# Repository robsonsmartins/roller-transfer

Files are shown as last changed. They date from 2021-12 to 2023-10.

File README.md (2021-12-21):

# PCB Roller Transfer Machine
The PCB Roller Transfer Machine (or Laminator Machine) is a machine designed to thermally transfer toner printed on paper to a blank Printed Circuit Board.

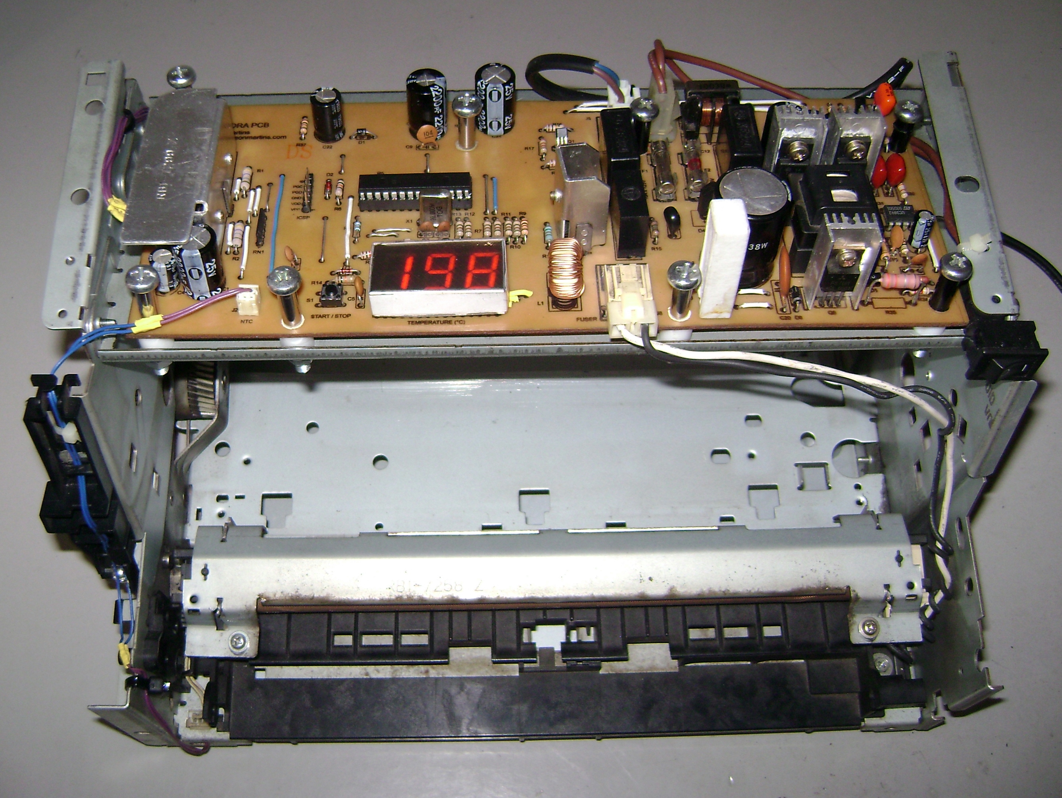
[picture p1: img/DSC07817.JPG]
PCB Roller Transfer Machine


Project site: [PCB Roller Transfer Machine Project](https://www.robsonmartins.com/content/eletr/projects/laminadora/)

[][cc-by-nc-sa]

This work is licensed under a
[Creative Commons Attribution-NonCommercial-ShareAlike 4.0 International License][cc-by-nc-sa].

[][cc-by-nc-sa]

[cc-by-nc-sa]: http://creativecommons.org/licenses/by-nc-sa/4.0/
[cc-by-nc-sa-image]: https://licensebuttons.net/l/by-nc-sa/4.0/88x31.png
[cc-by-nc-sa-shield]: https://img.shields.io/badge/License-CC%20BY--NC--SA%204.0-lightgrey.svg

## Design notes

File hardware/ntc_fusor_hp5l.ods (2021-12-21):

Tabela de Resistência X Temperatura do NTC do Fusor da HP 5L
Valor deRBalance (em Ω): |  | 18000
Temperatura (°C) | NTC Resistência (Ω) | Valor do ADC
20 | 440000,000 | 40
22 | 402072,277 | 44
24 | 368091,613 | 48
26 | 337586,262 | 52
28 | 310147,457 | 56
30 | 285420,188 | 61
32 | 263095,443 | 66
34 | 242903,659 | 71
36 | 224609,187 | 76
38 | 208005,600 | 82
40 | 192911,702 | 87
42 | 179168,131 | 93
44 | 166634,456 | 100
46 | 155186,703 | 106
48 | 144715,217 | 113
50 | 135122,842 | 120
52 | 126323,343 | 128
54 | 118240,047 | 135
56 | 110804,672 | 143
58 | 103956,307 | 151
60 | 97640,534 | 159
62 | 91808,656 | 168
64 | 86417,030 | 177
66 | 81426,490 | 185
68 | 76801,828 | 194
70 | 72511,356 | 204
72 | 68526,512 | 213
74 | 64821,517 | 223
76 | 61373,072 | 232
78 | 58160,093 | 242
80 | 55163,476 | 252
82 | 52365,890 | 262
84 | 49751,593 | 272
86 | 47306,268 | 282
88 | 45016,880 | 292
90 | 42871,548 | 303
92 | 40859,430 | 313
94 | 38970,621 | 324
96 | 37196,062 | 334
98 | 35527,461 | 344
100 | 33957,218 | 355
102 | 32478,361 | 365
104 | 31084,488 | 376
106 | 29769,713 | 386
108 | 28528,624 | 396
110 | 27356,233 | 406
112 | 26247,944 | 417
114 | 25199,517 | 427
116 | 24207,035 | 437
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

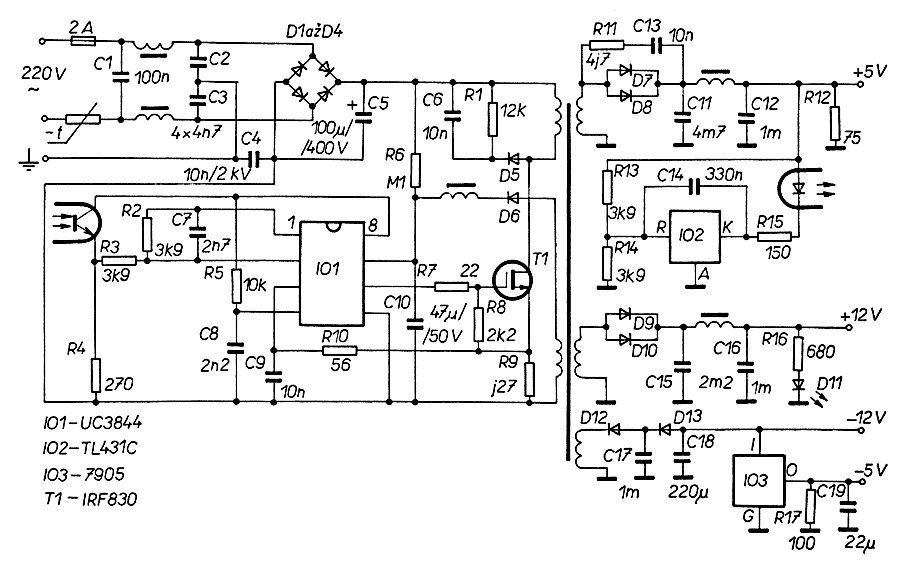
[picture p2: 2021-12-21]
hardware/psu_uc3844.gif

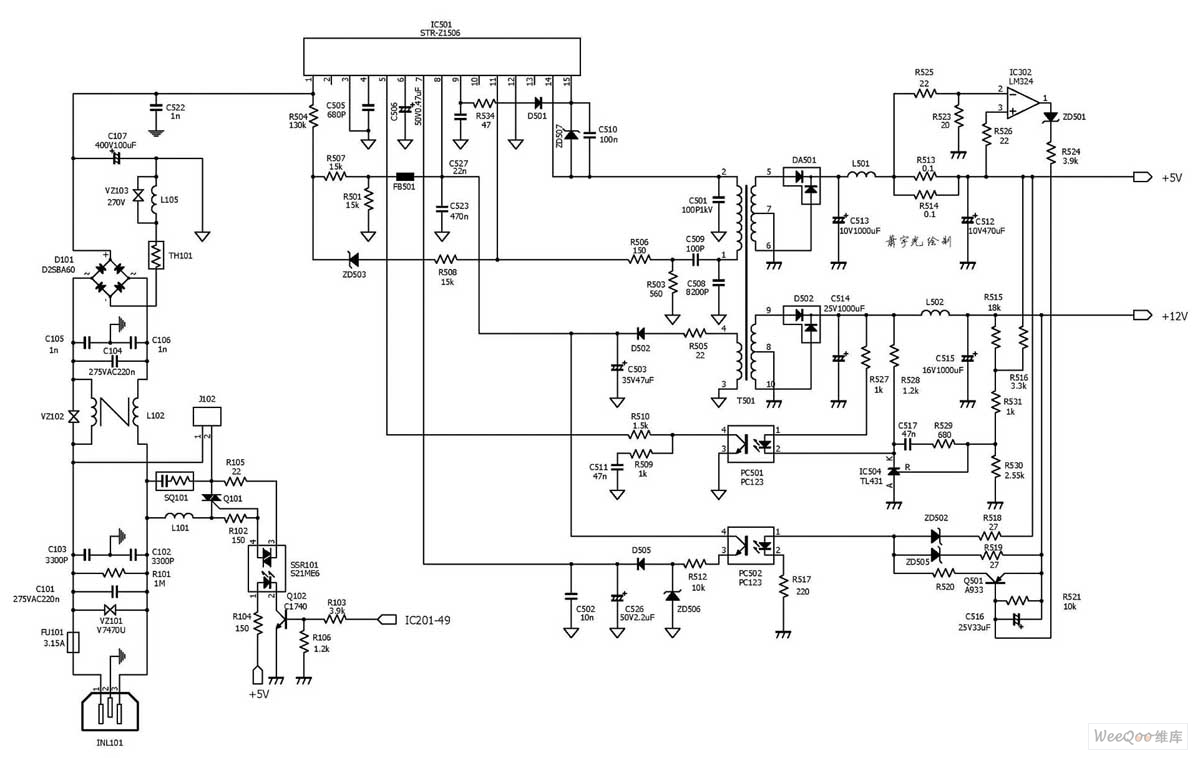
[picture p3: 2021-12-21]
hardware/psu_laserjet6l.jpg

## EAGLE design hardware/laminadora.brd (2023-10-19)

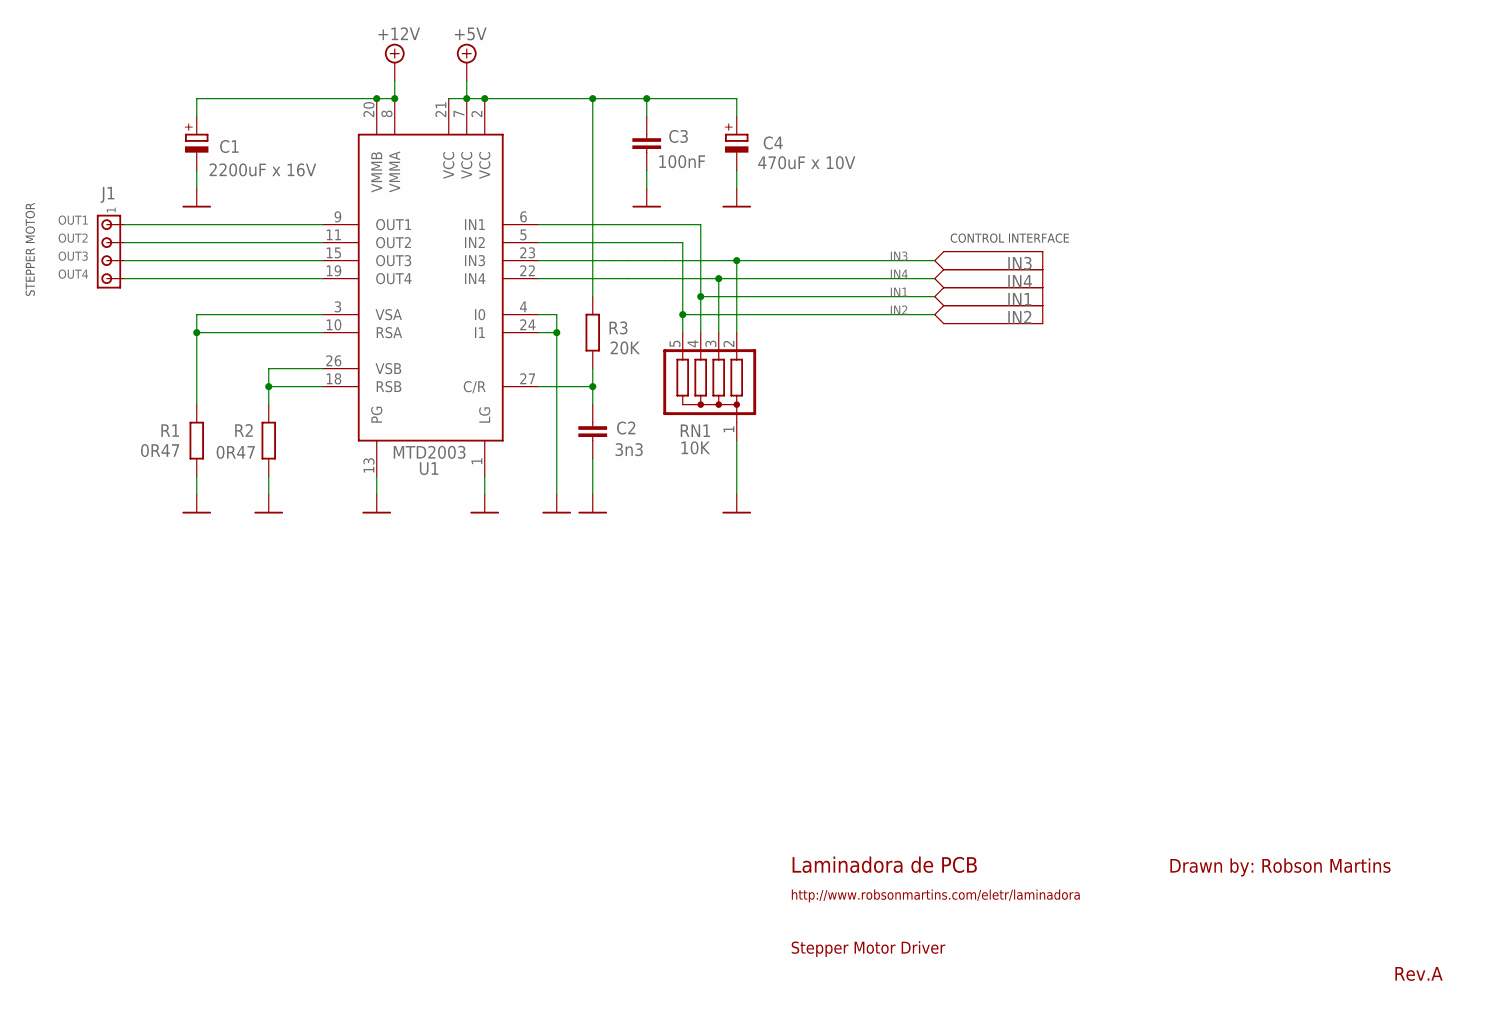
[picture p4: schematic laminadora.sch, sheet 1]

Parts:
C1: 2200uF x 16V; E5-13
C2: 3n3; C050-025X075
C3: 100nF; C050-025X075
C4: 470uF x 10V; E5-8,5
J1: A20-04
R1, R2: 0R47; 0309/12
R3: 20K; 0207/10
RN1: 10K; SIL5
U1: MTD2003; ZIP27SINK

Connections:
+5V: C3.1, C4.+, R3.2, U1.2 (VCC), U1.7 (VCC), U1.21 (VCC); also elsewhere on the board
+12V: C1.+, U1.8 (VMMA), U1.20 (VMMB); also elsewhere on the board
CR: C2.1, R3.1, U1.27 (C/R)
GND: C1.-, C2.2, C3.2, C4.-, R1.1, R2.1, RN1.1, U1.1 (LG), U1.4 (I0), U1.13 (PG), U1.24 (I1); also elsewhere on the board
IN1: RN1.4, U1.6 (IN1); also elsewhere on the board
IN2: RN1.5, U1.5 (IN2); also elsewhere on the board
IN3: RN1.2, U1.23 (IN3); also elsewhere on the board
IN4: RN1.3, U1.22 (IN4); also elsewhere on the board
OUT1: J1.1, U1.9 (OUT1)
OUT2: J1.2, U1.11 (OUT2)
OUT3: J1.3, U1.15 (OUT3)
OUT4: J1.4, U1.19 (OUT4)
SA: R1.2, U1.3 (VSA), U1.10 (RSA)
SB: R2.2, U1.18 (RSB), U1.26 (VSB)

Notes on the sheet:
STEPPER MOTOR
CONTROL INTERFACE
Drawn by: Robson Martins
Rev.A
Laminadora de PCB
Stepper Motor Driver
http://www.robsonmartins.com/eletr/laminadora

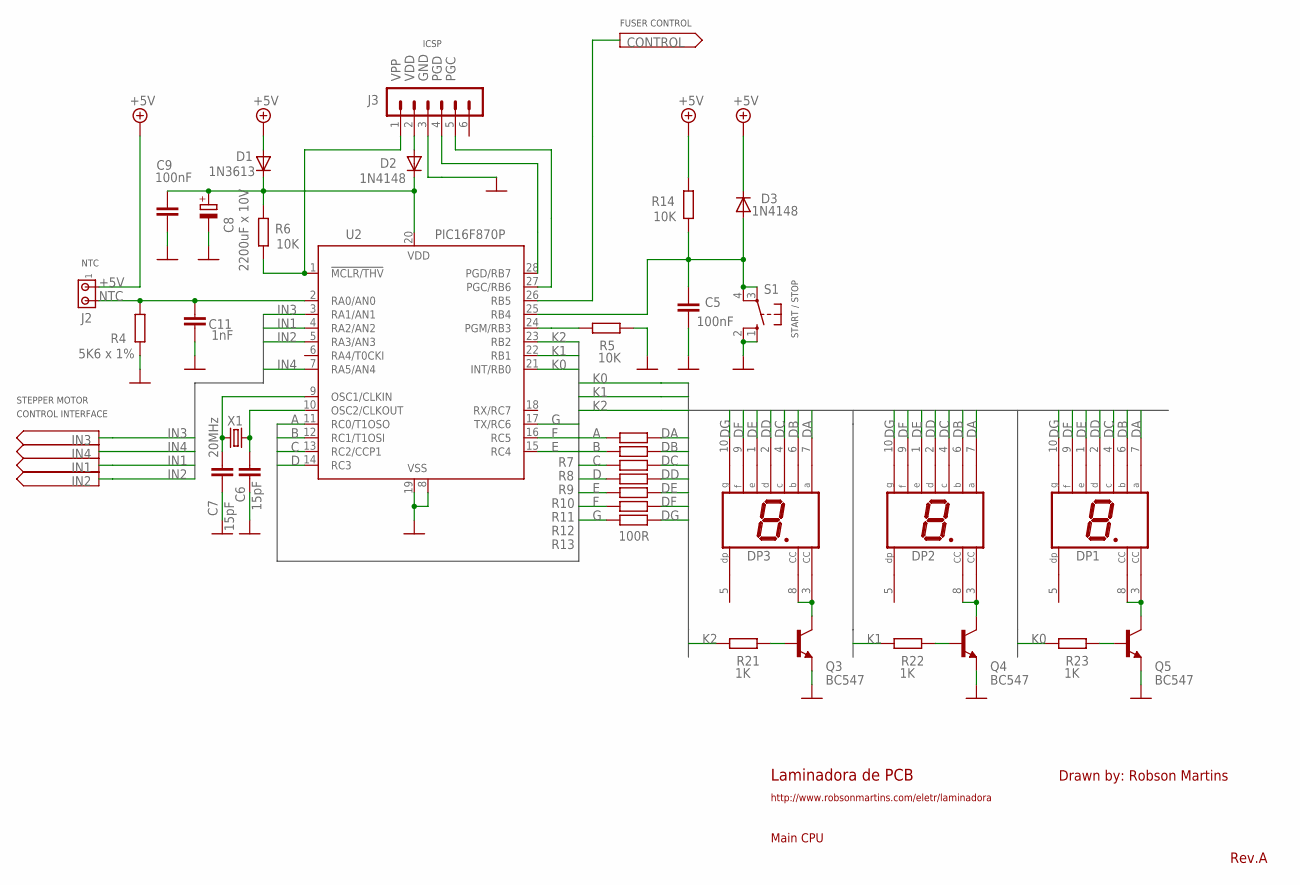
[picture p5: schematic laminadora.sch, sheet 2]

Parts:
C5, C9: 100nF; C050-025X075
C6, C7: 15pF; C025-025X050
C8: 2200uF x 10V; E5-13
C11: 1nF; C025-025X050
D1: 1N3613; DO35-7
D2, D3: 1N4148; DO35-7
DP1, DP2, DP3: HD-H103; HDSP-M
J2: A20-04; 10X02MTA
J3: MA06-1
Q3, Q4, Q5: BC547; TO92
R4: 5K6 x 1%; 0207/10
R5, R6, R14: 10K; 0207/10
R7, R8, R9, R10, R11, R12, R13: 100R; 0207/10
R21, R22, R23: 1K; 0207/10
S1: 10-XX; B3F-10XX
U2: PIC16F870P; DIL28-3
X1: 20MHz; HC49U-V

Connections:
+5V: D1.A, D3.C, J2.1, R14.2; also elsewhere on the board
A: R7.2, U2.11 (RC0/T1OSO)
B: R8.2, U2.12 (RC1/T1OSI)
C: R9.2, U2.13 (RC2/CCP1)
CONTROL: U2.26 (RB5); also elsewhere on the board
D: R10.2, U2.14 (RC3)
DA: DP1.7 (A), DP2.7 (A), DP3.7 (A), R7.1
DB: DP1.6 (B), DP2.6 (B), DP3.6 (B), R8.1
DC: DP1.4 (C), DP2.4 (C), DP3.4 (C), R9.1
DD: DP1.2 (D), DP2.2 (D), DP3.2 (D), R10.1
DE: DP1.1 (E), DP2.1 (E), DP3.1 (E), R11.1
DF: DP1.9 (F), DP2.9 (F), DP3.9 (F), R12.1
DG: DP1.10 (G), DP2.10 (G), DP3.10 (G), R13.1
E: R11.2, U2.15 (RC4)
F: R12.2, U2.16 (RC5)
G: R13.2, U2.17 (TX/RC6)
GND: C5.2, C6.2, C7.2, C8.-, C9.2, C11.2, J3.3, Q3.1 (E), Q4.1 (E), Q5.1 (E), R4.1, R5.1, S1.1 (S), S1.2 (S1), U2.8 (VSS), U2.19 (VSS); also elsewhere on the board
IN1: U2.4 (RA2/AN2); also elsewhere on the board
IN2: U2.5 (RA3/AN3); also elsewhere on the board
IN3: U2.3 (RA1/AN1); also elsewhere on the board
IN4: U2.7 (RA5/AN4); also elsewhere on the board
K0: R23.2, U2.21 (INT/RB0)
K1: R22.2, U2.22 (RB1)
K2: R21.2, U2.23 (RB2)
unnamed: DP3.3 (CC), DP3.8 (CC), Q3.3 (C)
unnamed: DP2.3 (CC), DP2.8 (CC), Q4.3 (C)
unnamed: DP1.3 (CC), DP1.8 (CC), Q5.3 (C)
unnamed: Q5.2 (B), R23.1
unnamed: Q4.2 (B), R22.1
unnamed: Q3.2 (B), R21.1
NTC: C11.1, J2.2, R4.2, U2.2 (RA0/AN0)
PGC: J3.5, U2.27 (PGC/RB6)
PGD: J3.4, U2.28 (PGD/RB7)
PGM: R5.2, U2.24 (PGM/RB3)
START_STOP: C5.1, D3.A, R14.1, S1.3, S1.4 (P1), U2.25 (RB4)
VDD: D2.A, J3.2
VDD_MICRO: C8.+, C9.1, D1.C, D2.C, R6.2, U2.20 (VDD)
VPP: J3.1, R6.1, U2.1 (!MCLR/THV)
XTAL1: C7.1, U2.9 (OSC1/CLKIN), X1.2
XTAL2: C6.1, U2.10 (OSC2/CLKOUT), X1.1

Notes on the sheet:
STEPPER MOTOR
CONTROL INTERFACE
Drawn by: Robson Martins
Rev.A
Laminadora de PCB
Main CPU
http://www.robsonmartins.com/eletr/laminadora
NTC
ICSP
START / STOP
FUSER CONTROL

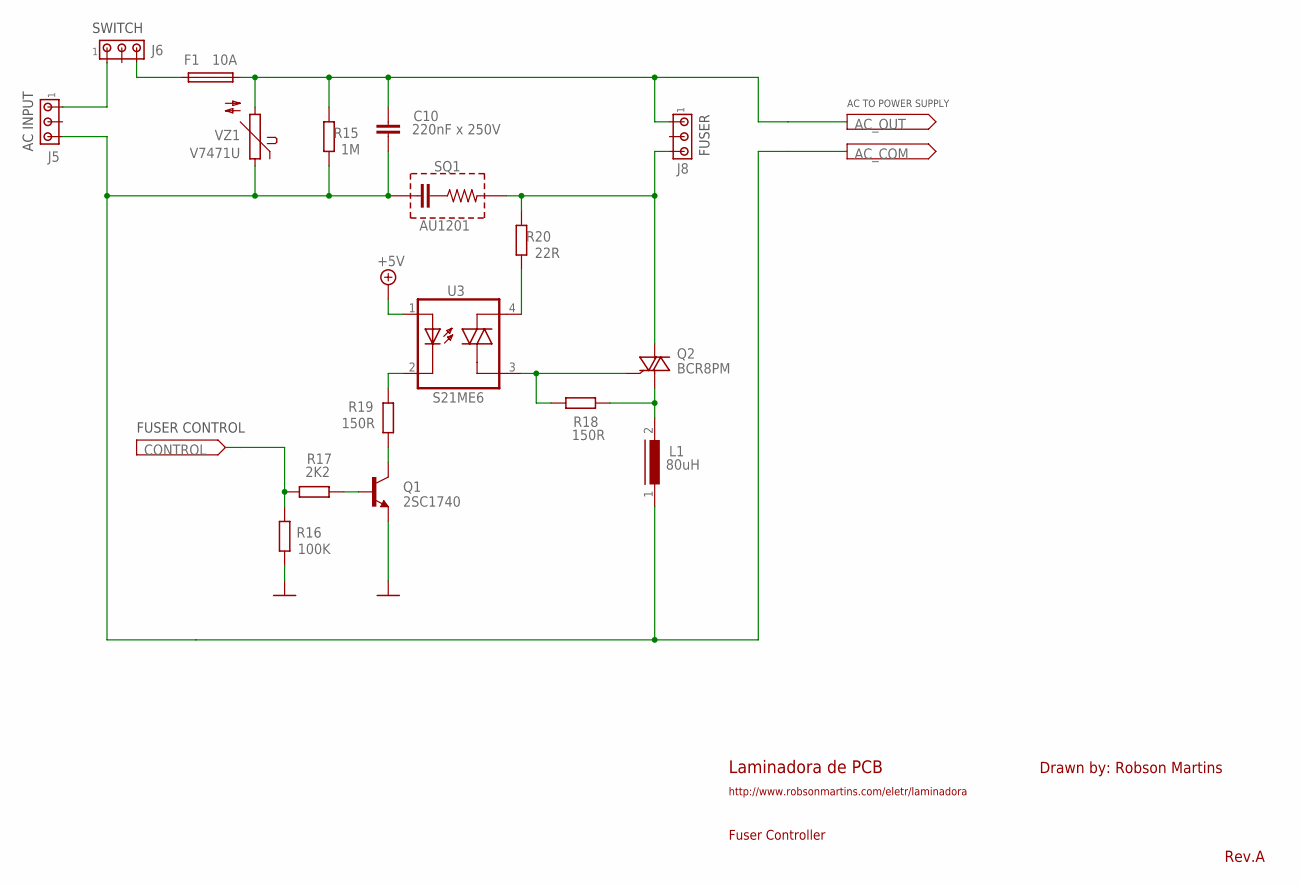
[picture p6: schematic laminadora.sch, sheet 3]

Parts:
C10: 220nF x 250V; C225-108X268
F1: 10A; SHK20L
J5, J6, J8: 794681-2; 1X3MTA
L1: 80uH; A26GFC
Q1: 2SC1740; TO92-ECB
Q2: BCR8PM; TO220BVSINK
R15: 1M; 0207/10
R16: 100K; 0207/10
R17: 2K2; 0207/10
R18, R19: 150R; 0207/10
R20: 22R; 0207/10
SQ1: AU1201; AU
U3: S21ME6; DIL4
VZ1: V7471U; S05K17

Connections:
+5V: U3.1 (A); also elsewhere on the board
AC_COM: C10.2, J5.3, L1.1, R15.1, SQ1.1 (2), VZ1.1; also elsewhere on the board
AC_FUSER: J8.3, Q2.T2 (A2), R20.2, SQ1.2 (3)
AC_IN: J5.1, J6.1
AC_OUT: C10.1, F1.2A, J8.1, R15.2, VZ1.2; also elsewhere on the board
AC_SW: F1.1A, J6.3
CONTROL: R16.2, R17.2; also elsewhere on the board
GATE: Q2.G, R18.2, U3.3 (A1)
GND: Q1.E, R16.1; also elsewhere on the board
unnamed: R20.1, U3.4 (A2)
unnamed: L1.2, Q2.T1 (A1), R18.1
unnamed: R19.2, U3.2 (C)
unnamed: Q1.C, R19.1
unnamed: Q1.B, R17.1

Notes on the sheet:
Drawn by: Robson Martins
Rev.A
Laminadora de PCB
Fuser Controller
http://www.robsonmartins.com/eletr/laminadora
AC INPUT
SWITCH
FUSER
FUSER CONTROL
AC TO POWER SUPPLY

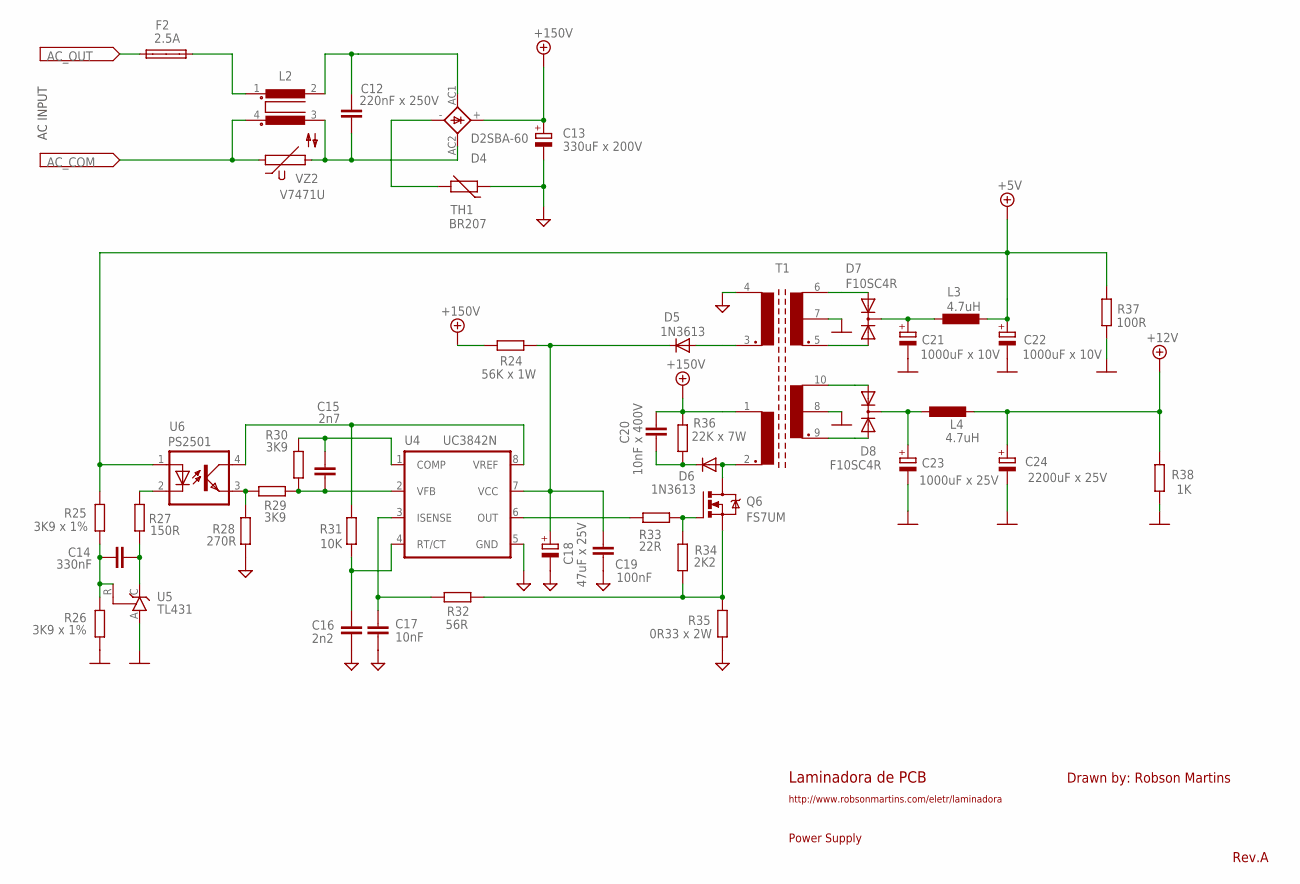
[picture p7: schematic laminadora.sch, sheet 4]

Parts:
C12: 220nF x 250V; C225-108X268
C13: 330uF x 200V; EB22,5D
C14: 330nF; C075-042X103
C15: 2n7; C050-030X075
C16: 2n2; C050-030X075
C17: 10nF; C050-030X075
C18: 47uF x 25V; E5-6
C19: 100nF; C050-030X075
C20: 10nF x 400V; C102-043X133
C21, C22: 1000uF x 10V; E5-10,5
C23: 1000uF x 25V; E5-13
C24: 2200uF x 25V; E5-13
D4: D2SBA-60; FBU4
D5, D6: 1N3613; DO35-7
D7, D8: F10SC4R; TO220ABS
F2: 2.5A; SHK20L
L2: MFE
L3, L4: 4.7uH; 6000-XXXX-RC
Q6: FS7UM; TO220BV
R24: 56K x 1W; 0309/12
R25, R26: 3K9 x 1%; 0207/10
R27: 150R; 0207/10
R28: 270R; 0207/10
R29, R30: 3K9; 0207/10
R31: 10K; 0207/10
R32: 56R; 0207/10
R33: 22R; 0207/10
R34: 2K2; 0207/10
R35: 0R33 x 2W; 0411/15
R36: 22K x 7W; 0617V
R37: 100R; 0207/10
R38: 1K; 0207/10
T1: SK69ABD2
TH1: BR207; R-7,5
U4: UC3842N; DIL08
U5: TL431; TO92-CLP
U6: PS2501; DIL04
VZ2: V7471U; S05K17

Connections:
5VNR: C21.+, D7.C, L3.1
12VNR: C23.+, D8.C, L4.1
+5V: C22.+, L3.2, R25.2, R37.2, U6.1 (A); also elsewhere on the board
+12V: C24.+, L4.2, R38.2; also elsewhere on the board
+150V: C13.+, C20.1, D4.+, R24.2, R36.2, T1.1 (3)
AC_COM: L2.4 (3), VZ2.1; also elsewhere on the board
AC_OUT: F2.1A; also elsewhere on the board
AGND: C13.-, C16.2, C17.2, C18.-, C19.2, R28.1, R35.1, T1.4 (1), TH1.1, U4.5 (GND)
GND: C21.-, C22.-, C23.-, C24.-, R26.1, R37.1, R38.1, T1.7 (9), T1.8 (6), U5.A; also elsewhere on the board
unnamed: F2.2A, L2.1
unnamed: R27.1, U6.2 (C)
unnamed: R28.2, R29.2, U6.3 (EMIT)
unnamed: C14.2, R27.2, U5.C
unnamed: C14.1, R25.1, R26.2, U5.R
unnamed: D7.A1, T1.6 (10)
unnamed: C20.2, D6.C, R36.1
unnamed: D5.A, T1.3 (2)
unnamed: D7.A2, T1.5 (8)
unnamed: D8.A1, T1.10 (7)
unnamed: D8.A2, T1.9 (5)
PWR_16VCC: C18.+, C19.1, D5.C, R24.1, U4.7 (VCC)
PWR_AC1: C12.1, D4.AC1 (AC2), L2.2
PWR_AC2: C12.2, D4.AC2 (AC1), L2.3 (4), VZ2.2
PWR_COMP: C15.1, R30.2, U4.1 (COMP)
PWR_D_FET: D6.A, Q6.D, T1.2 (4)
PWR_FET_OUT: R33.2, U4.6 (OUT)
PWR_G_FET: Q6.G, R33.1, R34.2
PWR_ISENSE: C17.1, R32.2, U4.3 (ISENSE)
PWR_RTCT: C16.1, R31.1, U4.4 (RT/CT)
PWR_S_FET: Q6.S, R32.1, R34.1, R35.2
PWR_VFB: C15.2, R29.1, R30.1, U4.2 (VFB)
PWR_VNEG: D4.-, TH1.2
PWR_VREF: R31.2, U4.8 (VREF), U6.4 (COL)

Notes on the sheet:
Drawn by: Robson Martins
Rev.A
Laminadora de PCB
Power Supply
http://www.robsonmartins.com/eletr/laminadora
AC INPUT

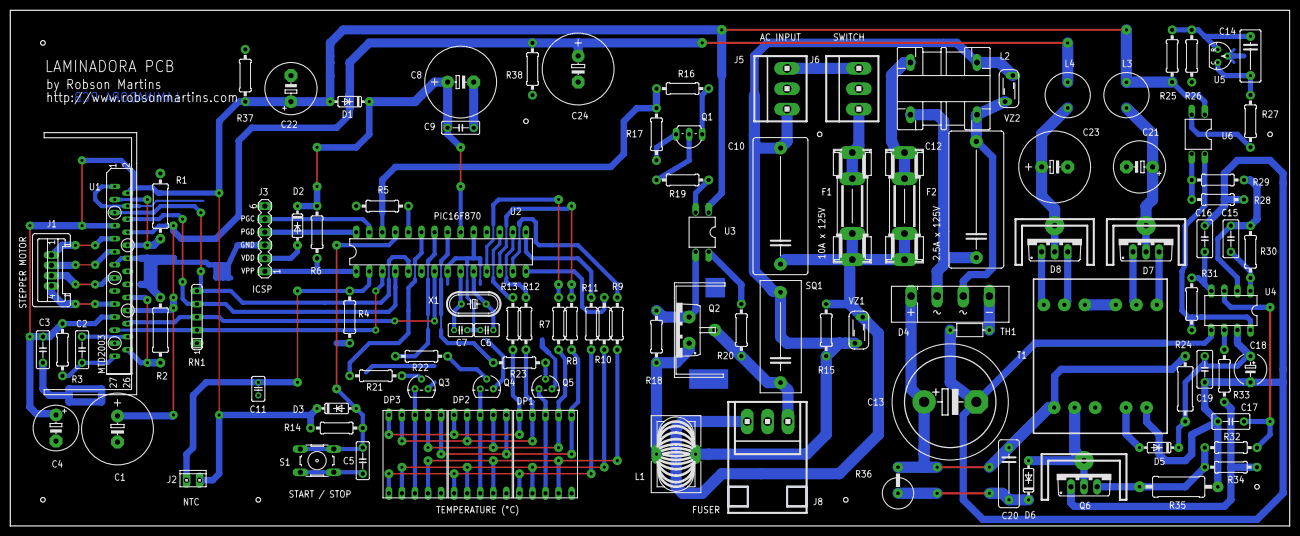
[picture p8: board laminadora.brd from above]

Board: 2 copper layers, 248.9 x 100.3 mm, 105 parts (0 on the bottom side), 87 nets.

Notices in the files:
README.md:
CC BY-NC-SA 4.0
